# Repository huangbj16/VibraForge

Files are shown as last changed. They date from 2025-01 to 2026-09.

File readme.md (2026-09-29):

<h1 align="center">VibraForge</h1>

<p align="center">
  <strong>A Scalable Prototyping Toolkit for Creating Spatialized Vibrotactile Feedback Systems</strong>
</p>

<p align="center">
  
  
  
  
</p>

---

VibraForge is an open-source toolkit for building **spatialized vibrotactile (haptic) feedback systems**. Small vibration actuators (LRA / VCA) are daisy-chained into scalable arrays and driven wirelessly over Bluetooth Low Energy by an ESP32-based control unit. This repository shares the complete design — mechanical, electrical, firmware, and software — so you can reproduce, modify, and integrate the toolkit into your own research and applications.

The data flow through the system is:

```
Authoring tool (GUI Editor / Unity / Python)  →  Python BLE server  →  ESP32 Control Unit (BLE)  →  chain of Vibration Units (LRA/VCA)
```

## Table of Contents

- [Repository Structure](#repository-structure)
- [Getting Started](#getting-started)
- [Running the Software](#running-the-software)
- [Hardware Notes & Debugging](#hardware-notes--debugging)
- [Getting a Dev Kit](#getting-a-dev-kit)
- [Contributing](#contributing)
- [License](#license)
- [Citation](#citation)

## Repository Structure

| Directory | Description |
|---|---|
| [Electrical_Design/](Electrical_Design/) | PCB design files (EasyEDA / Altium / Gerber) and microcontroller firmware for the control and vibration units. |
| [Mechanical_Design/](Mechanical_Design/) | 3D-printable CAD (STL / 3MF) enclosures, caps, mounts, and rings. |
| [Software_Design/](Software_Design/) | Python BLE servers and the Unity Engine integration API. |
| [GUI_Editor/](GUI_Editor/) | PyQt6 desktop app for designing, simulating, and playing haptic waveforms. |
| [manufacturing.md](manufacturing.md) | End-to-end build guide — pipeline flowchart, full BOM, PCB ordering, firmware, and assembly. |

Each subfolder contains its own `readme` with detailed, component-specific instructions.

## Getting Started

There are two ways to get the hardware, depending on whether you already have a kit:

### ▸ I have a dev kit

If you received a hardware dev kit from the authors, it ships with a printed **[Quickstart Guide](quickstart_guide.pdf)** — follow it to get up and running quickly.

### ▸ I want to build it myself

If you don't have a kit, the **[Manufacturing Guide](manufacturing.md)** walks you through the entire build end-to-end: a step-by-step pipeline flowchart, a full bill of materials, ordering assembled PCBs from JLCPCB, flashing firmware, 3D-printing the enclosures, and final assembly.

At a high level:

1. **Fabricate the boards** — order the PCBs from the Gerber files in [Electrical_Design/](Electrical_Design/) and flash the firmware (Arduino for the control unit, MPLAB X for the vibration units).
2. **Print the enclosures** — print the CAD parts in [Mechanical_Design/](Mechanical_Design/).
3. **Assemble and test** — wire the chains and run the bring-up test (below).

> Prefer to skip fabrication? You can request a ready-made kit — see [Getting a Dev Kit](#getting-a-dev-kit).

## Running the Software

Once the hardware is assembled:

1. **Bring-up test** — verify BLE control with [`Python_Test.py`](Software_Design/Python_Server/Python_Test.py). Enter vibration parameters manually on the command line. Ensure the `CHARACTERISTIC_UUID` and control unit name match the values in the control unit's Arduino firmware:

   ```bash
   python Python_Test.py -uuid CUSTOM_UUID -name CONTROL_UNIT_NAME

   # default uuid = 'f22535de-5375-44bd-8ca9-d0ea9ff9e410'
   # default name = 'QT Py ESP32-S3'
   ```

2. **Design waveforms** — once the test passes, use the [GUI Editor](GUI_Editor/) to experiment with different vibration waveforms (Sine, PWM, Triangle, Saw, etc.).

3. **Integrate with Unity** — to drive vibrations from a game engine, use the [Unity Engine API](Software_Design/Unity_Engine_API/).

For details on each program, see the [Software_Design](Software_Design/) and [GUI_Editor](GUI_Editor/) readmes.

## Hardware Notes & Debugging

### Control Unit

- **Connector orientation matters.** The order of the four chain connectors is shown in the figure below, and the USB port should face **left**. Installing a connector in the wrong direction may short the ESP32 MCU.
- If the MCU misbehaves for no clear reason, try a [factory reset](https://learn.adafruit.com/adafruit-qt-py-esp32-s3/factory-reset).

<p align="center">Control unit assembly and connector orientation</p>

### Vibration Unit

- **Addressing.** Unit addresses start at **0** and are unique per chain position. Up to 16 units per chain: chain 1 → `0–15`, chain 2 → `16–31`, and so on.
- **Orientation matters.** With the programming pins on top, the **input is on the left** and the **output is on the right**. Do not reverse the order, or the driver board may be damaged by a short.
- **Status LED.** Each driver PCB has one RGB status LED (NeoPixel). It stays off while the unit is idle, lights up when the unit receives a "Start" command and should be vibrating, with the color indicating the intensity level, and turns off again on "Stop". It does not indicate power on its own. This is useful for checking MCU status while debugging.

<p align="center">Vibration unit chain addressing and orientation</p>

## Getting a Dev Kit

Interested in using the toolkit but would rather not build the hardware yourself? Request a development kit from the authors by filling out [this Google Form](https://forms.gle/6aN7M9MWAf4sLqWE6).

## Contributing

Contributions and bug reports are welcome! If you run into a problem or spot a bug while using the toolkit, please [open an issue](../../issues) — the authors will try to resolve it as soon as possible. Pull requests for improvements are also appreciated.

## License

This project is released under the [MIT License](LICENSE).

## Citation

If you use VibraForge in your research, we would appreciate it if you can cite our CHI 2025 paper:

```bibtex
@inproceedings{huang2025vibraforge,
  title={VibraForge: A Scalable Prototyping Toolkit For Creating Spatialized Vibrotactile Feedback Systems},
  author={Huang, Bingjian and Ren, Siyi and Luo, Yuewen and Cheng, Qilong and Cai, Hanfeng and Sang, Yeqi and Sousa, Mauricio and Dietz, Paul H and Wigdor, Daniel},
  booktitle={Proceedings of the 2025 CHI Conference on Human Factors in Computing Systems},
  pages={1--18},
  year={2025}
}
```

Have fun with the toolkit! 🎉

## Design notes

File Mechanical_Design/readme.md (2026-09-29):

# Mechanical Design

This folder contains CAD files for control units and vibration units. In our lab environment, parts are printed with PLA materials using 0.4mm nozzles on [Bambu Lab X1C 3D Printer](store.bambulab.com/collections/3d-printer/products/x1-carbon). Other printers with higher precision should also satisfy the requirements.

- Control_Unit_Large
- Control_Unit_Small — two enclosure variants with the same 49 × 47 mm footprint. Print each enclosure together with its matching cap.
  - **With battery** (`Enclosure_with_Battery.stl`, `Cap_with_Battery.stl`): the original design, with space for a battery. The enclosure is 22 mm tall and the cap 8.5 mm. STL only. These files were previously named `Enclosure.stl` and `Cap.stl`.
  - **Battery-free** (`Enclosure_Battery_Free.stl`, `Cap_Battery_Free.stl`) — **used in the dev kit**: a newer, slimmer design for a control unit powered over USB with no battery. The enclosure is 8.5 mm shallower (13.5 mm tall) and the cap is 11.5 mm tall. Editable STEP files are included.
- Vibration_Unit_LRAX
- Vibration_Unit_LRAZ
- Vibration_Unit_VCA

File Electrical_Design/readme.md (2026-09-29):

# Electrical Engineering Section ##

The electrical engineering section includes PCB design files for control units and vibration units, and main programs for microcontrollers. All PCB design were initially finished in [EasyEDA](https://easyeda.com/) and later exported to different formats. If you want to manufacture the board with PCB factories such as [JLCPCB](https://jlcpcb.com/) or [PCBWay](https://www.pcbway.com/), simply use the Gerber files. If you want to revise the design, Import the design files into EasyEDA Editor or Altium Designer.

Control units include the large unit and the small unit, with different ESP32 microcontrollers. The large unit uses [Adafruit ESP32 Feather V2](https://learn.adafruit.com/adafruit-esp32-feather-v2). The small unit uses [Adafruit QT Py ESP32-S3](https://learn.adafruit.com/adafruit-qt-py-esp32-s3). The Arduino programs are very similar, except the software serial pins are configured differently.

Arduino Library Rrquirements:
- [Arduino ESP32 support](https://github.com/espressif/arduino-esp32)
- [SoftwareSerial for ESP32](https://github.com/plerup/espsoftwareserial)

Vibration units include LRA and VCA, all using the PIC16F18313 8-pin microcontroller. The main program is the same across all vibration units. To program / reprogram the MCU, you need to download the [MPLAB X IDE](https://www.microchip.com/en-us/tools-resources/develop/mplab-x-ide) and buy the  [MPLAB® PICkit™ 5 In-Circuit Debugger](https://www.microchip.com/en-us/development-tool/pg164150). add the main program (`Vibration_Unit.c`) and the NeoPixel driver (`neopixel_control.c`, `neopixel_control.h`) to an MPLAB X project, connect the programming pins from the debugger to the top of the PCB board, following this [quickstart guideline](https://ww1.microchip.com/downloads/aemDocuments/documents/DEV/ProductDocuments/Brochures/MPLAB-PICkit-5-In-Circuit-Debugger-Quick-Start-Guide-50003478.pdf).

- Control_Unit
  - Large_Unit
  - Small_Unit
  - Main_Program_Arduino
    - BLE_peripheral_ESP32V2
    - BLE_peripheral_QTPyS3
- Vibration_Unit
  - Board_LRA
  - Board_VCA
  - Main_Program_MPLABXIDE
    - tests
  - Schematic

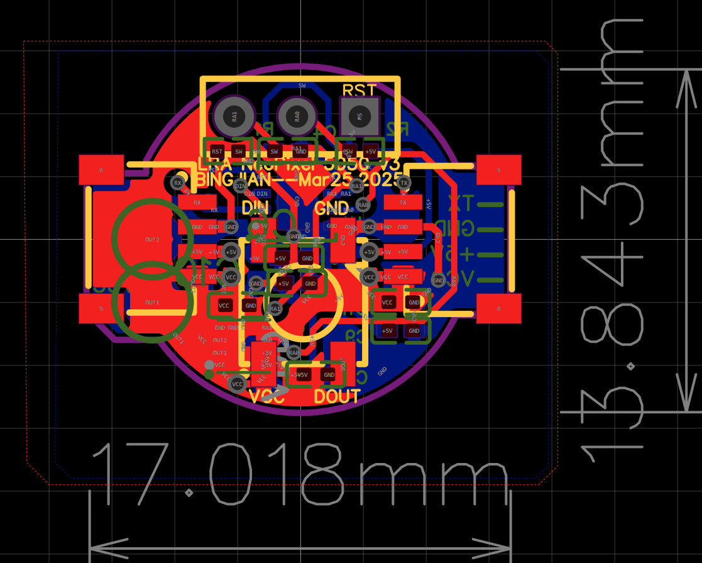
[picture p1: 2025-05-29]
Electrical_Design/Vibration_Unit/Board_LRA/Board_LRA_Screenshot.png

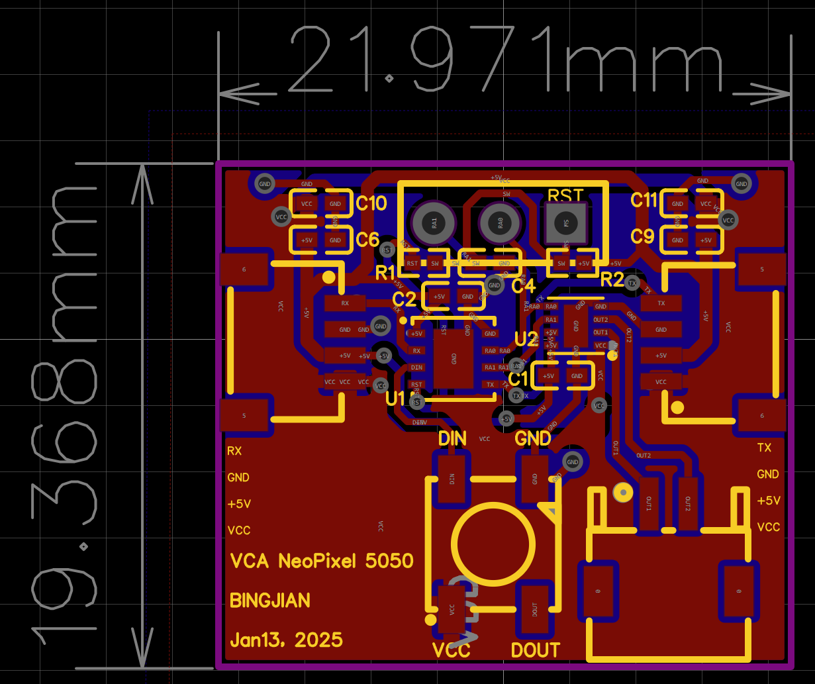
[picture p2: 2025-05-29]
Electrical_Design/Vibration_Unit/Board_VCA/Board_VCA_Screenshot.png

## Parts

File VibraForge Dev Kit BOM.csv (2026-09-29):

Item | # needed for a dev kit | Link
Packaging
fold box | 1 | https://www.amazon.ca/dp/B08G8CLKNH?ref_=ppx_hzsearch_conn_dt_b_fed_asin_title_1
3D print holder | 1 | https://www.amazon.ca/dp/B0FD1LFGZT (matte PLA filament)
sleeves | 1 | https://www.amazon.ca/dp/B0DGQ37KB7?ref=ppx_yo2ov_dt_b_fed_asin_title&th=1
rubber band | 1 | random
user manual | 1 | paper print
Control Unit
3D print enclosure (battery-free) | 1 | https://www.amazon.ca/dp/B0FGD7DJ4K (transparent PLA filament)
3D print cap (battery-free) | 1 | https://www.amazon.ca/dp/B0FGD7DJ4K (transparent PLA filament)
Controller PCB (v2.0) | 1 | https://jlcpcb.com/ (order as assembled PCBA)
Adafruit QT Py ESP32-S3 | 1 | https://www.adafruit.com/product/5426
Vibration Unit
LRA actuators | 10 | https://www.digikey.com/en/products/detail/jie-yi-electronics-limited/JYLRA9595X/22519430 (or Jinlong Machinery; bulk: contact author)
vibration PCB | 10 | https://jlcpcb.com/ (order as assembled PCBA)
3D print mount | 10 | https://www.amazon.ca/dp/B0FGD7DJ4K (transparent PLA filament)
cap | 10 | https://www.amazon.ca/dp/B0FGD7DJ4K (transparent PLA filament)
enclosure | 10 | https://www.amazon.ca/dp/B0FGD7DJ4K (transparent PLA filament)
ring | 10 | https://www.amazon.ca/dp/B0FGD7DJ4K (transparent PLA filament)
STEMMA QT / Qwiic JST SH 4-pin Cable - 100mm Long | 40 | https://www.adafruit.com/product/4210
MISC
PicKit5 programmer | 1 | https://www.digikey.com/en/products/detail/microchip-technology/PG164150/19915398

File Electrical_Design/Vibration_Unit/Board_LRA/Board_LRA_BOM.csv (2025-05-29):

ID | Name | Designator | Footprint | Quantity | Manufacturer Part | Manufacturer | Supplier | Supplier Part | Price
1 | CONN-SMD_YTC1P-3015-01 | U6,U4 | CONN-SMD_YTC1P-3015-01 | 2 | YTC1P-3015-01 | YIYUAN(怡远) | LCSC | C5221293 | 0.112
2 | 1uF | C1 | C0402 | 1 | CL05A105KA5NQNC | SAMSUNG(三星) | LCSC | C52923 | 0.003
3 | 100nF | C2,C4 | C0402_NEW | 2 | CL05B104KO5NNNC | SAMSUNG(三星) | LCSC | C1525 | 0.001
4 | 300Ω | R1 | R0402 | 1 | 0402WGF3000TCE | UNI-ROYAL(厚声) | LCSC | C25102 | 0.001
5 | 10kΩ | R2 | R0402 | 1 | 0402WGF1002TCE | UNI-ROYAL(厚声) | LCSC | C25744 | 0.001
6 | PIC16F18313-E/RF | U1 | DFN-8_L3.0-W3.0-P0.65-BL-EP | 1 | PIC16F18313-E/RF | MICROCHIP(美国微芯) | LCSC | C635328 | 2.104
7 | DRV8837DSGR | U2 | WSON-8_L2.0-W2.0-P0.50-TL-EP | 1 | DRV8837DSGR | TI(德州仪器) | LCSC | C39159 | 0.141
8 | LED-SMD_4P-L5.0-W5.0-TL-2 | U3 | LED-SMD_4P-L5.0-W5.0-TL-2 | 1 | SKC6812RGBW-BW-B | 欧思科光电 | LCSC | C5380878 | 0.141
9 | SM04B-SRSS-TB (LF)(SN) | CN5,CN6 | CONN-SMD_4P-P1.00_SM04B-SRSS-TB-LF-SN | 2 | SM04B-SRSS-TB(LF)(SN) | JST | LCSC | C160404 | 0.191
10 | C0402 | C6,C9,C10,C11 | C0402 | 4 | GRM155R60J226ME11D | muRata(村田) | LCSC | C415703 | 0.037

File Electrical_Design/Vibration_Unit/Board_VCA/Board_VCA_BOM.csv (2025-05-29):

ID | Name | Designator | Footprint | Quantity | Manufacturer Part | Manufacturer | Supplier | Supplier Part | Price
1 | LED-SMD_4P-L5.0-W5.0-TL-2 | U3 | LED-SMD_4P-L5.0-W5.0-TL-2 | 1 | SKC6812RGBW-BW-B | 欧思科光电 | LCSC | C5380878 | 0.141
2 | S2B-ZR-SM4A-TF(LF)(SN) | CN2 | CONN-SMD_S2B-ZR-SM4A | 1 | S2B-ZR-SM4A-TF(LF)(SN) | JST | LCSC | C265329 | 0.173
3 | 1uF | C1 | C0402 | 1 | CL05A105KA5NQNC | SAMSUNG(三星) | LCSC | C52923 | 0.003
4 | 100nF | C2,C4 | C0402_NEW | 2 | CL05B104KO5NNNC | SAMSUNG(三星) | LCSC | C1525 | 0.001
5 | SM04B-SRSS-TB (LF)(SN) | CN5,CN6 | CONN-SMD_4P-P1.00_SM04B-SRSS-TB-LF-SN | 2 | SM04B-SRSS-TB(LF)(SN) | JST | LCSC | C160404 | 0.191
6 | 300Ω | R1 | R0402 | 1 | 0402WGF3000TCE | UNI-ROYAL(厚声) | LCSC | C25102 | 0.001
7 | 10kΩ | R2 | R0402 | 1 | 0402WGF1002TCE | UNI-ROYAL(厚声) | LCSC | C25744 | 0.001
8 | PIC16F18313-E/RF | U1 | DFN-8_L3.0-W3.0-P0.65-BL-EP | 1 | PIC16F18313-E/RF | MICROCHIP(美国微芯) | LCSC | C635328 | 2.104
9 | DRV8837DSGR | U2 | WSON-8_L2.0-W2.0-P0.50-TL-EP | 1 | DRV8837DSGR | TI(德州仪器) | LCSC | C39159 | 0.141
10 | C0402 | C6,C9,C10,C11 | C0402 | 4 | GRM155R60J226ME11D | muRata(村田) | LCSC | C415703 | 0.037

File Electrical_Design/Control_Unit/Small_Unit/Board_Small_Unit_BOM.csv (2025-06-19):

ID | Name | Designator | Footprint | Quantity | Manufacturer Part | Manufacturer | Supplier | Supplier Part | Price
1 | B5819W_C8598 | D3 | SOD-123_L2.7-W1.6-LS3.7-RD-1 | 1 | B5819W SL | CJ(江苏长电/长晶) | LCSC | C8598 | 0.023
2 | 22uF | C5 | CAP-SMD_BD5.0-L5.3-W5.3-FD | 1 | RVT1E220M0505 | HONOR(荣誉) | LCSC | C15848 | 0.029
3 | 22uH | L2 | IND-SMD_L6.0-W6.0_SWPA6045S | 1 | SWPA6045S220MT | Sunlord(顺络) | LCSC | C83454
4 | S2B-PH-K-S-GW | U4,U5 | CONN-TH_S2B-PH-K-S-GW | 2 | S2B-PH-K-S-GW | JST | LCSC | C157932 | 0.197
5 | 1uF | C2,C1 | C0805 | 2 | CL21B105KBFNNNE | SAMSUNG(三星) | LCSC | C28323 | 0.009
6 | 10nF | C3,C7 | C0402 | 2 | CL05B103KB5NNNC | SAMSUNG(三星) | LCSC | C15195 | 0.001
7 | 10uF | C4 | C0603 | 1 | CL10A106KP8NNNC | SAMSUNG(三星) | LCSC | C19702 | 0.006
8 | 2.2uF | C6 | C0603 | 1 | CL10A225KO8NNNC | SAMSUNG(三星) | LCSC | C23630 | 0.006
9 | 120uF | C9 | CAP-SMD_BD6.3-L6.6-W6.6-FD | 1 | 10SVPC120MV | PANASONIC(松下) | LCSC | C178336 | 0.959
10 | SS34_C8678 | D2,D1 | SMA_L4.3-W2.6-LS5.2-RD | 2 | SS34 | MDD(辰达半导体) | LCSC | C8678 | 0.028
11 | LM22675MRX-5.0/NOPB | U1 | SO-8_L4.9-W3.9-P1.27-LS6.0-BL-EP5.1 | 1 | LM22675MRX-5.0/NOPB | TI(德州仪器) | LCSC | C431550 | 1.155
12 | LT1763CS8-5#TRPBF | U3 | SO-8_L4.9-W3.9-P1.27-LS5.9-BL | 1 | LT1763CS8-5#TRPBF | ADI(亚德诺) | LCSC | C579850 | 5.477
13 | 22uF | C8 | C0805 | 1 | CL21A226MAYNNNE | SAMSUNG(三星) | LCSC | C602037 | 0.023
14 | SM04B-SRSS-TB (LF)(SN) | CN3,CN4,CHAIN#1,CN2 | CONN-SMD_4P-P1.00_SM04B-SRSS-TB-LF-SN | 4 | SM04B-SRSS-TB(LF)(SN) | JST | LCSC | C160404 | 0.191
15 | A2541HWV-7P | H1,H2 | HDR-TH_7P-P2.54-V_A2541HWV-7P | 2 | A2541HWV-7P | CJT(长江连接器) | LCSC | C225504 | 0.13
16 | SZYY0805YG | LED13 | LED0805-R-RD_GREEN | 1 | SZYY0805YG | yongyu(永裕光电) | LCSC | C434435 | 0.014
17 | 10kΩ | R13 | R0805 | 1 | 0805W8F1002T5E | UNI-ROYAL(厚声) | LCSC | C17414 | 0.002

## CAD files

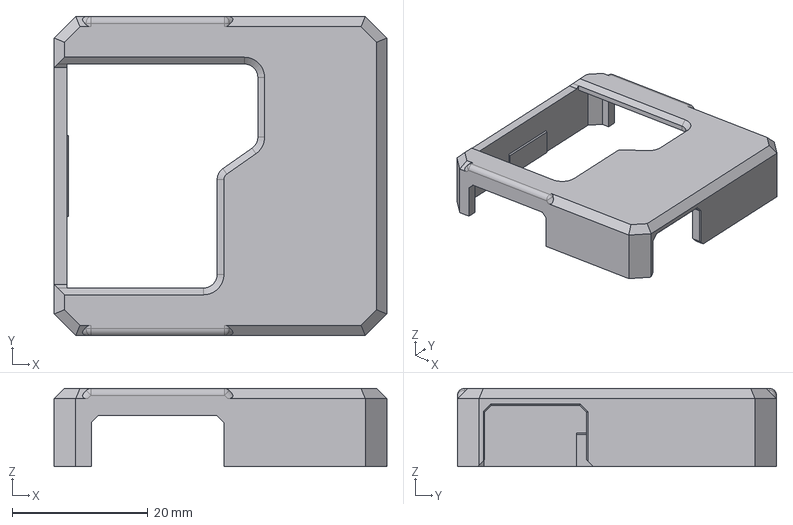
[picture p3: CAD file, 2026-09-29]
Mechanical_Design/Control_Unit_Small/Cap_Battery_Free.step
49.0 x 47.0 x 11.5 mm

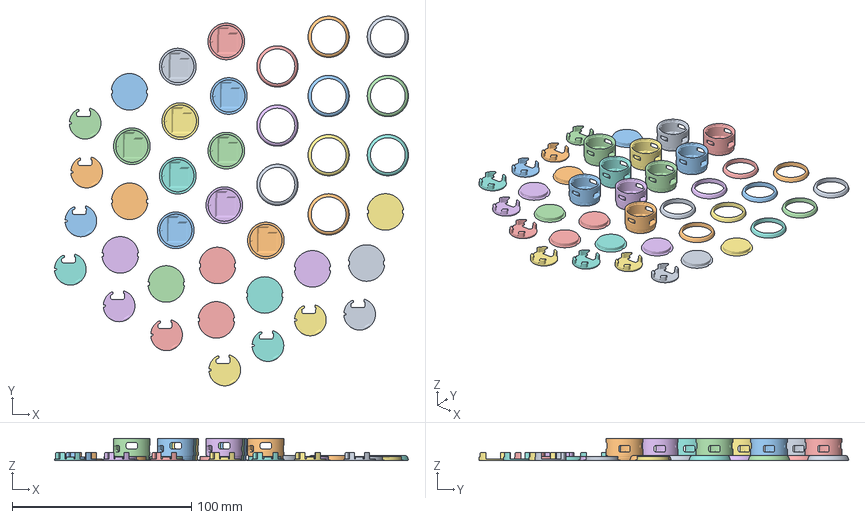
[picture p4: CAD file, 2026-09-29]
Mechanical_Design/Vibration_Unit_LRAX/printing_plate_unitx10.3mf
197.7 x 206.5 x 12.5 mm
Ring.stl x 10
Enclosure.stl x 10
Cap.stl x 10
Mount.stl x 10

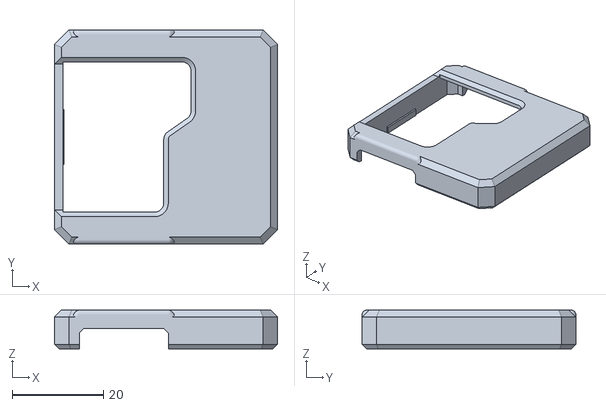
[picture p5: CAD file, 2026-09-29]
Mechanical_Design/Control_Unit_Small/Cap_with_Battery.stl
49.0 x 47.0 x 8.50

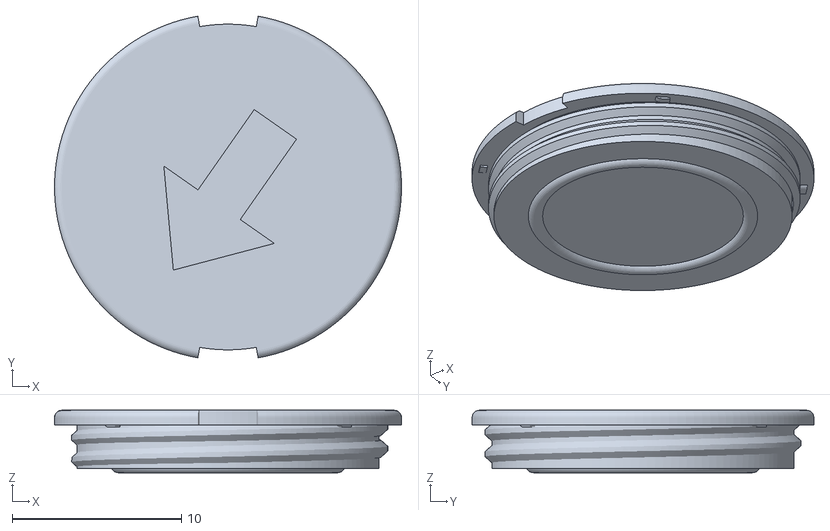
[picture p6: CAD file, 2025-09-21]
Mechanical_Design/Vibration_Unit_LRAX/Cap.stl
20.5 x 20.2 x 3.70

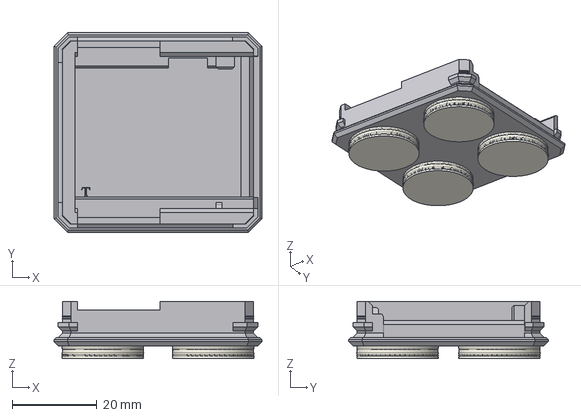
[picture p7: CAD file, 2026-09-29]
Mechanical_Design/Control_Unit_Small/Enclosure_Battery_Free.step
49.0 x 47.0 x 13.5 mm

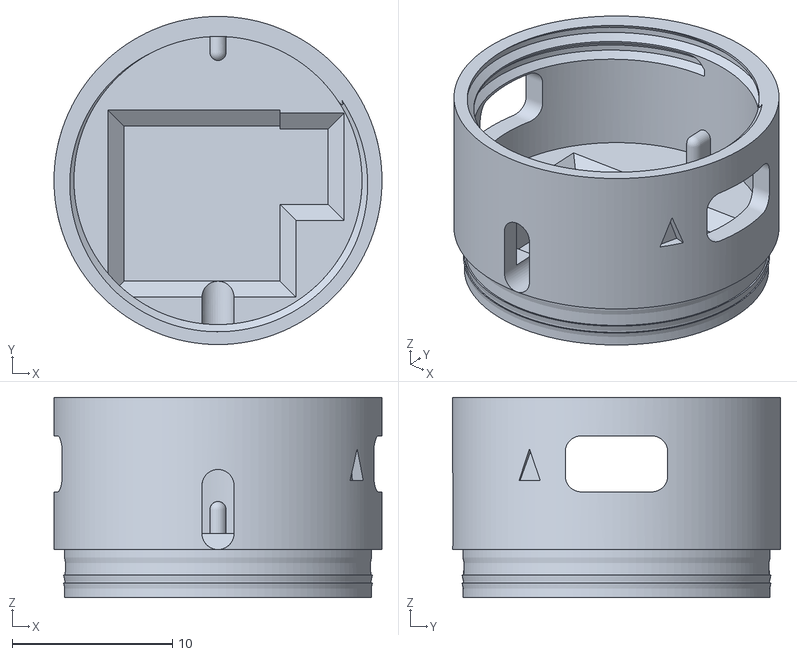
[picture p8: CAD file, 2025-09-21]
Mechanical_Design/Vibration_Unit_LRAX/Enclosure.stl
20.5 x 20.5 x 12.5

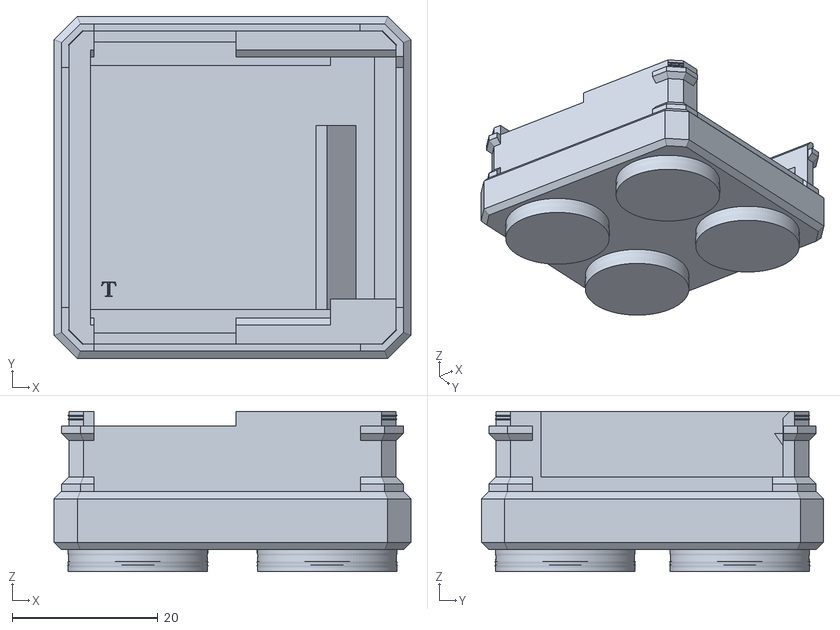
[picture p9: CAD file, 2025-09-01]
Mechanical_Design/Control_Unit_Small/Enclosure_with_Battery.stl
49.0 x 47.0 x 22.0

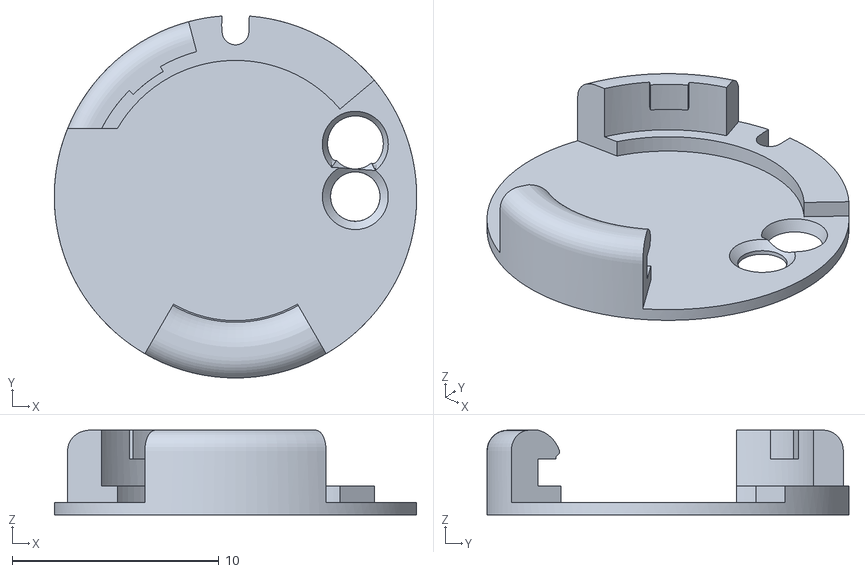
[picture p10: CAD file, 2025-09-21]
Mechanical_Design/Vibration_Unit_LRAX/Mount.stl
17.5 x 17.5 x 4.10

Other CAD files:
Mechanical_Design/Control_Unit_Small/Cap_Battery_Free.stl
Mechanical_Design/Control_Unit_Small/Enclosure_Battery_Free.stl

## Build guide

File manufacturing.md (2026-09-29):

# Manufacturing Guide

This document describes how to manufacture one **VibraForge** development kit end-to-end, so you can build a working spatialized vibrotactile system yourself. It covers PCB ordering, component sourcing, firmware programming, 3D-printed parts, and final assembly.

This guide targets the **standard dev-kit configuration**:

- **Control Unit** — 1×, based on the **Adafruit QT Py ESP32-S3** (the "Small" control unit). A Bluetooth hub that drives up to four serial chains of actuators.
- **Vibration Units** — 10×, each a PIC-microcontroller driver board carrying one **LRA-X** actuator (linear resonant actuator, in-plane axis). Units are daisy-chained; each chain supports up to 16 units.
- **Packaging** — box, holder, sleeves, and printed manual for shipping a complete kit.

> Source files: PCB + firmware in [Electrical_Design/](Electrical_Design/), CAD in [Mechanical_Design/](Mechanical_Design/).

---

## 1. Manufacturing Pipeline (DAG)

The three sub-assemblies — **Packaging**, **Control Unit**, and **Vibration Units** — are fully independent and can be built in parallel. They converge only at final kit assembly and bring-up test.

```mermaid
---
title: VibraForge Dev Kit — Manufacturing Pipeline
---
flowchart LR
    START([" Start<br/>build one dev kit "]):::milestone

    %% ===================== CONTROL UNIT (top lane) =====================
    subgraph CU ["🎛️ Control Unit ×1"]
        direction LR
        C1[/"Order Controller PCB v2.0 · JLCPCB<br/>assembled PCBA · ~7 business days<br/>⏱ ORDER EARLY"/]:::buy
        C2[/"Buy QT Py ESP32-S3<br/>Adafruit / DigiKey"/]:::buy
        C3["3D-print battery-free<br/>enclosure + cap<br/>100% infill · 0.2 mm layer"]:::print
        C4["Program ESP32<br/>Arduino IDE"]:::program
        C2 --> C4
        C4 --> C5["Mount ESP32 on PCB"]:::assemble
        C1 --> C5
        C5 --> C6["Assemble into<br/>enclosure + cap"]:::assemble
        C3 --> C6
        C6 --> CU_DONE(["✔ Control Unit ready"]):::milestone
    end

    %% ===================== VIBRATION UNITS (middle lane) =====================
    subgraph VU ["📳 Vibration Units ×10"]
        direction LR
        V1[/"Source LRA-X actuators ×10<br/>Jinlong Machinery / DigiKey"/]:::buy
        V2[/"Order Vibration PCB ×10 · JLCPCB<br/>assembled PCBA · ~7 business days<br/>⏱ ORDER EARLY"/]:::buy
        V4["3D-print mount + cap<br/>+ enclosure + ring · ×10 each<br/>100% infill · 0.12 mm layer"]:::print
        V5["Program PIC16F18313<br/>PICkit 5 · flash firmware<br/>wiring → Sec 3.3.1"]:::program
        V2 --> V5
        V5 --> V6["Assemble · NO SOLDERING<br/>actuator via pogo-pin contact<br/>PCB into enclosure/mount/ring/cap"]:::assemble
        V1 --> V6
        V4 --> V6
        V6 --> VU_DONE(["✔ Vibration Units ready"]):::milestone
    end

    %% ===================== PACKAGING (bottom lane) =====================
    subgraph PKG ["📦 Packaging"]
        direction LR
        P1[/"Buy fold box ×1<br/>Amazon"/]:::buy
        P2[/"Buy sleeves ×1<br/>Amazon"/]:::buy
        P3[/"Buy rubber band ×1"/]:::buy
        P4["3D-print holder ×1"]:::print
        P5["Print user manual<br/>on paper ×1"]:::print
        P1 --> PKG_DONE
        P2 --> PKG_DONE
        P3 --> PKG_DONE
        P4 --> PKG_DONE
        P5 --> PKG_DONE
        PKG_DONE(["✔ Packaging ready"]):::milestone
    end

    %% ===================== INTEGRATION (right column) =====================
    subgraph INT ["🔗 Integration & Test"]
        direction TB
        BUYCABLE[/"Buy JST SH 4-pin cables ×40<br/>Adafruit / DigiKey"/]:::buy
        WIRE["Wire chains<br/>units in series via JST cables<br/>plug chains into control unit"]:::assemble
        TEST["Bring-up test<br/>Python_Test.py over BLE"]:::test
        PACK["Pack into box<br/>holder · sleeves · manual"]:::assemble
        DONE([" ✔ Dev kit complete "]):::milestone
        BUYCABLE --> WIRE
        WIRE --> TEST
        TEST --> PACK
        PACK --> DONE
    end

    START --> C1
    START --> V1
    START --> P1

    CU_DONE --> WIRE
    VU_DONE --> BUYCABLE
    PKG_DONE --> PACK

    %% ===================== STYLING =====================
    classDef buy       fill:#E3F2FD,stroke:#1565C0,stroke-width:1px,color:#0D47A1;
    classDef print     fill:#E8F5E9,stroke:#2E7D32,stroke-width:1px,color:#1B5E20;
    classDef program   fill:#FFF3E0,stroke:#EF6C00,stroke-width:1px,color:#E65100;
    classDef assemble  fill:#F3E5F5,stroke:#6A1B9A,stroke-width:1px,color:#4A148C;
    classDef test      fill:#FCE4EC,stroke:#AD1457,stroke-width:1px,color:#880E4F;
    classDef milestone fill:#263238,stroke:#263238,stroke-width:1px,color:#FFFFFF;
    style CU  fill:#FAFAFA,stroke:#CFD8DC,stroke-width:1px,color:#37474F;
    style VU  fill:#FAFAFA,stroke:#CFD8DC,stroke-width:1px,color:#37474F;
    style PKG fill:#FAFAFA,stroke:#CFD8DC,stroke-width:1px,color:#37474F;
    style INT fill:#F5F5F5,stroke:#90A4AE,stroke-width:1.5px,color:#37474F;
```

**Critical path:** the two JLCPCB orders (Controller PCB and Vibration PCBs) have the longest lead time at **~7 business days** — place both first, then print 3D parts, buy off-the-shelf items, and program firmware while you wait.

---

## 2. Bill of Materials (one dev kit)

> The full parts list is also available as a spreadsheet: [VibraForge Dev Kit BOM.csv](VibraForge%20Dev%20Kit%20BOM.csv).
>
> **Filament:** print the packaging **holder** in [matte PLA](https://www.amazon.ca/dp/B0FD1LFGZT); print **all other parts** (control-unit and vibration-unit enclosures, caps, mounts, rings) in [transparent PLA](https://www.amazon.ca/dp/B0FGD7DJ4K).

### Packaging
| Item | Qty | Source |
|---|-----|---|
| Fold box | 1 | [Amazon](https://www.amazon.ca/dp/B08G8CLKNH) |
| Sleeves | 1 | [Amazon](https://www.amazon.ca/dp/B0DGQ37KB7) |
| Rubber band | 1 | Any |
| 3D-print holder | 1 | Print in-house |
| User manual | 1 | Paper print |

### Control Unit (×1)
| Item | Qty | Source |
|---|-----|---|
| Controller PCB v2.0 (assembled) | 1 | JLCPCB (PCBA) |
| Adafruit QT Py ESP32-S3 | 1 | [Adafruit #5426](https://www.adafruit.com/product/5426) / DigiKey |
| 3D-print enclosure (battery-free) | 1 | Print in-house |
| 3D-print cap (battery-free) | 1 | Print in-house |

### Vibration Unit (×10)
| Item | Qty | Source |
|---|-----|---|
| LRA-X actuator | 10 | Jinlong Machinery / [DigiKey JYLRA9595X](https://www.digikey.com/en/products/detail/jie-yi-electronics-limited/JYLRA9595X/22519430) — for bulk orders, contact the author |
| Vibration PCB (assembled) | 10 | JLCPCB (PCBA) |
| 3D-print mount | 10 | Print in-house |
| 3D-print cap | 10 | Print in-house |
| 3D-print enclosure | 10 | Print in-house |
| 3D-print ring | 10 | Print in-house |
| STEMMA QT / Qwiic JST SH 4-pin cable, 100mm | 40 | [Adafruit #4210](https://www.adafruit.com/product/4210) / DigiKey |

### Miscellaneous (tools — one per builder, not per kit)
| Item | Qty | Source |
|---|-----|---|
| MPLAB PICkit 5 programmer | 1 | [DigiKey PG164150](https://www.digikey.com/en/products/detail/microchip-technology/PG164150/19915398) |

> Both PCBs are ordered **fully assembled (PCBA)** from JLCPCB, so no hand-soldering of SMT components is required. The orderable BOM and placement files are provided for both boards:
> - Small Control Unit: [Board_Small_Unit_BOM.csv](Electrical_Design/Control_Unit/Small_Unit/Board_Small_Unit_BOM.csv), [Board_Small_Unit_CPL.csv](Electrical_Design/Control_Unit/Small_Unit/Board_Small_Unit_CPL.csv)
> - LRA Vibration Unit: [Board_LRA_BOM.csv](Electrical_Design/Vibration_Unit/Board_LRA/Board_LRA_BOM.csv), [Board_LRA_CPL.csv](Electrical_Design/Vibration_Unit/Board_LRA/Board_LRA_CPL.csv)

---

## 3. Step-by-Step Manufacturing

### 3.1 Packaging

All three sub-assemblies are independent — packaging can be prepared any time.

1. **Buy** the fold box, sleeves, and a rubber band (see BOM links).
2. **3D-print** the packaging holder (1×).
3. **Print the user manual** on paper.
4. Set these aside for final kit assembly (§3.5).

### 3.2 Control Unit (×1)

1. **Order the Controller PCB v2.0** from [JLCPCB](https://jlcpcb.com/) as an **assembled PCBA** — upload the Gerber, BOM, and CPL from [Small_Unit/](Electrical_Design/Control_Unit/Small_Unit/) so JLCPCB places all components. **Lead time ~7 business days — order this first.**
2. **Buy the Adafruit QT Py ESP32-S3** ([#5426](https://www.adafruit.com/product/5426), Adafruit or DigiKey).
3. **3D-print** the **battery-free** control-unit enclosure and cap — [Enclosure_Battery_Free.stl](Mechanical_Design/Control_Unit_Small/Enclosure_Battery_Free.stl) and [Cap_Battery_Free.stl](Mechanical_Design/Control_Unit_Small/Cap_Battery_Free.stl) — normal settings with **100% infill** and a regular **0.2mm layer height**. The unit is powered over USB. The folder also contains the older `*_with_Battery` variant, which the dev kit does not use (see the [Mechanical Design readme](Mechanical_Design/readme.md)).
4. **Program the ESP32 with Arduino IDE** (see §3.2.1).
5. **Assemble:** mount the programmed ESP32 onto the controller PCB, then fit the PCB into the enclosure and close with the cap.
6. **Orientation matters:** the four chain connectors must be installed in the correct order and the **USB port must face left** — see [Figures/control_unit.png](Figures/control_unit.png). Reversing a connector can short the ESP32.

#### 3.2.1 Control Unit Firmware (Arduino)

1. Install the [Arduino ESP32 core](https://github.com/espressif/arduino-esp32) and the [ESP32 SoftwareSerial](https://github.com/plerup/espsoftwareserial) library. The sketch also uses `ArduinoJson` and `Adafruit_NeoPixel`.
2. Open [BLE_peripheral_QTPyS3.ino](Electrical_Design/Control_Unit/Main_Program_Arduino/BLE_peripheral_QTPyS3/BLE_peripheral_QTPyS3.ino).
3. Note the BLE identifiers — these must match your host software:
   - `SERVICE_UUID = f10016f6-542b-460a-ac8b-bbb0b2010599`
   - `CHARACTERISTIC_UUID = f22535de-5375-44bd-8ca9-d0ea9ff9e410`
   - Device name: `QT Py ESP32-S3`
4. The four chains are driven on `subchain_pins = {18, 17, 9, 8}`.
5. Select the QT Py ESP32-S3 board and upload over USB. If it misbehaves, [factory-reset the board](https://learn.adafruit.com/adafruit-qt-py-esp32-s3/factory-reset).

### 3.3 Vibration Units (×10)

1. **Source the LRA-X actuators** (10×) from **Jinlong Machinery**, or buy from [DigiKey (JYLRA9595X)](https://www.digikey.com/en/products/detail/jie-yi-electronics-limited/JYLRA9595X/22519430). For bulk orders, contact the author.
2. **Order the Vibration PCBs** (10×) from JLCPCB as **assembled PCBA** — upload the Gerber, BOM, and CPL from [Board_LRA/](Electrical_Design/Vibration_Unit/Board_LRA/). **Lead time ~7 business days — order early.**
3. **Buy the JST cables:** STEMMA QT / Qwiic JST SH 4-pin, 100mm (40× — [Adafruit #4210](https://www.adafruit.com/product/4210) or DigiKey). These form the chain links.
4. **3D-print** all four parts — mount, cap, enclosure, ring (10× each) — normal settings with **100% infill** and **0.12mm layer height** (files in [Vibration_Unit_LRAX/](Mechanical_Design/Vibration_Unit_LRAX/)).
5. **Program each PIC16F18313 MCU** with the PICkit 5 (§3.3.1). The same firmware is flashed to every unit — no per-unit address to set.
6. **Assemble — no soldering required!** The LRA-X actuator makes contact with the PCB via **pogo pins**. Seat the actuator, PCB, mount, and ring into the enclosure and close with the cap; the ring/mount hold the actuator against the pogo-pin contacts.
7. **Orientation matters:** with the programming pins on top, **input is on the left, output on the right**. Do not reverse — the driver board can be damaged by a short. See [Figures/vibration_unit.png](Figures/vibration_unit.png).
8. **Status LED (debug aid):** each board has one RGB NeoPixel. It is off while idle and lights up when the board receives a "Start" command and should be vibrating, with the color indicating the intensity level. It does not indicate power on its own.

#### 3.3.1 Vibration Unit Firmware (PICkit 5)

The **same firmware** runs on every vibration unit: [Vibration_Unit.c](Electrical_Design/Vibration_Unit/Main_Program_MPLABXIDE/Vibration_Unit.c) plus the NeoPixel driver [neopixel_control.c](Electrical_Design/Vibration_Unit/Main_Program_MPLABXIDE/neopixel_control.c) / [neopixel_control.h](Electrical_Design/Vibration_Unit/Main_Program_MPLABXIDE/neopixel_control.h) (PIC16F18313, 32 MHz HFINTOSC). There is **no per-unit address to program** — a unit's address is determined automatically by its position in the chain at runtime (chain 1 → 0–15, chain 2 → 16–31, etc.).

1. Install [MPLAB X IDE](https://www.microchip.com/en-us/tools-resources/develop/mplab-x-ide) and connect the [PICkit 5](https://www.digikey.com/en/products/detail/microchip-technology/PG164150/19915398).
2. Connect the PICkit 5 programming wires to the header on the **top** of the vibration PCB as shown below:

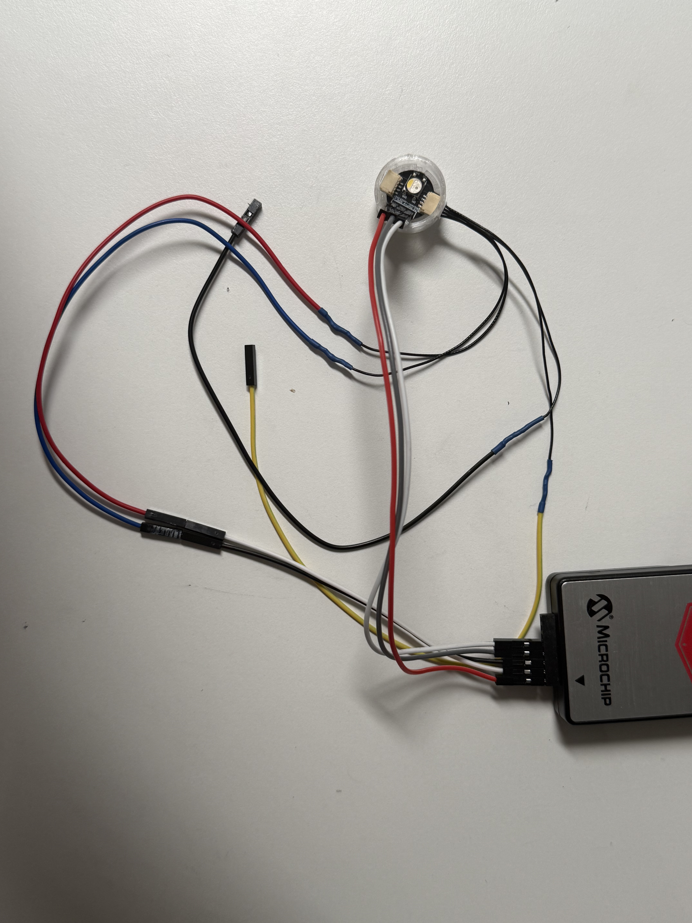
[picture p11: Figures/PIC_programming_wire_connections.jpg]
PICkit 5 to vibration unit programming wire connections
   

3. Create an MPLAB X project for the PIC16F18313 with the XC8 compiler and add `Vibration_Unit.c`, `neopixel_control.c`, and `neopixel_control.h` (not the standalone programs in `tests/`). Build and flash the firmware to each of the 10 boards. Every board gets the identical program.

### 3.4 Chain Wiring & Bring-up Test

1. **Daisy-chain the vibration units:** connect each unit's **output** to the next unit's **input** using the JST SH cables, keeping input-left / output-right orientation consistent.
2. Plug each chain's first unit into the corresponding chain connector on the control unit (respect connector order, §3.2).
3. Power the control unit via USB.
4. **Bring-up test** — install `pip install bleak`, then from [Software_Design/Python_Server/](Software_Design/Python_Server/):
   ```bash
   python Python_Test.py -uuid f22535de-5375-44bd-8ca9-d0ea9ff9e410 -name "QT Py ESP32-S3"
   ```
5. Send a command to a known address and confirm the target unit's NeoPixel lights up and it vibrates.

### 3.5 Final Kit Assembly

1. Place the tested control unit and 10 vibration units into the 3D-printed holder.
2. Add the sleeves and secure with the rubber band.
3. Insert the printed user manual and pack everything into the fold box.

Once verified, the kit can be driven with the [GUI Editor](GUI_Editor/), the [Unity API](Software_Design/Unity_Engine_API/), or [Python_Play_Command.py](Software_Design/Python_Server/Python_Play_Command.py).

---

## 4. Quick Checklist

**Order early (long lead time):**
- [ ] Controller PCB v2.0 — JLCPCB assembled (~7 business days)
- [ ] Vibration PCBs ×10 — JLCPCB assembled (~7 business days)

**Control Unit**
- [ ] QT Py ESP32-S3 purchased
- [ ] Battery-free enclosure + cap printed (100% infill, 0.2mm)
- [ ] ESP32 flashed with Arduino firmware
- [ ] Assembled (USB faces left, connector order verified)

**Vibration Units (×10)**
- [ ] LRA-X actuators sourced (Jinlong / DigiKey)
- [ ] Mount / cap / enclosure / ring printed (100% infill, 0.12mm)
- [ ] Each PIC flashed with firmware (PICkit 5, no address to set)
- [ ] Assembled — no soldering (pogo-pin actuator contact, input-left/output-right)

**Packaging**
- [ ] Fold box + sleeves + rubber band bought
- [ ] Holder printed, manual printed

**Integration**
- [ ] JST cables ×40 purchased
- [ ] Chains wired and plugged into control unit
- [ ] Passed `Python_Test.py` bring-up test
- [ ] Packed into box

Have fun building the toolkit! If you hit a problem, open an issue in the repository.

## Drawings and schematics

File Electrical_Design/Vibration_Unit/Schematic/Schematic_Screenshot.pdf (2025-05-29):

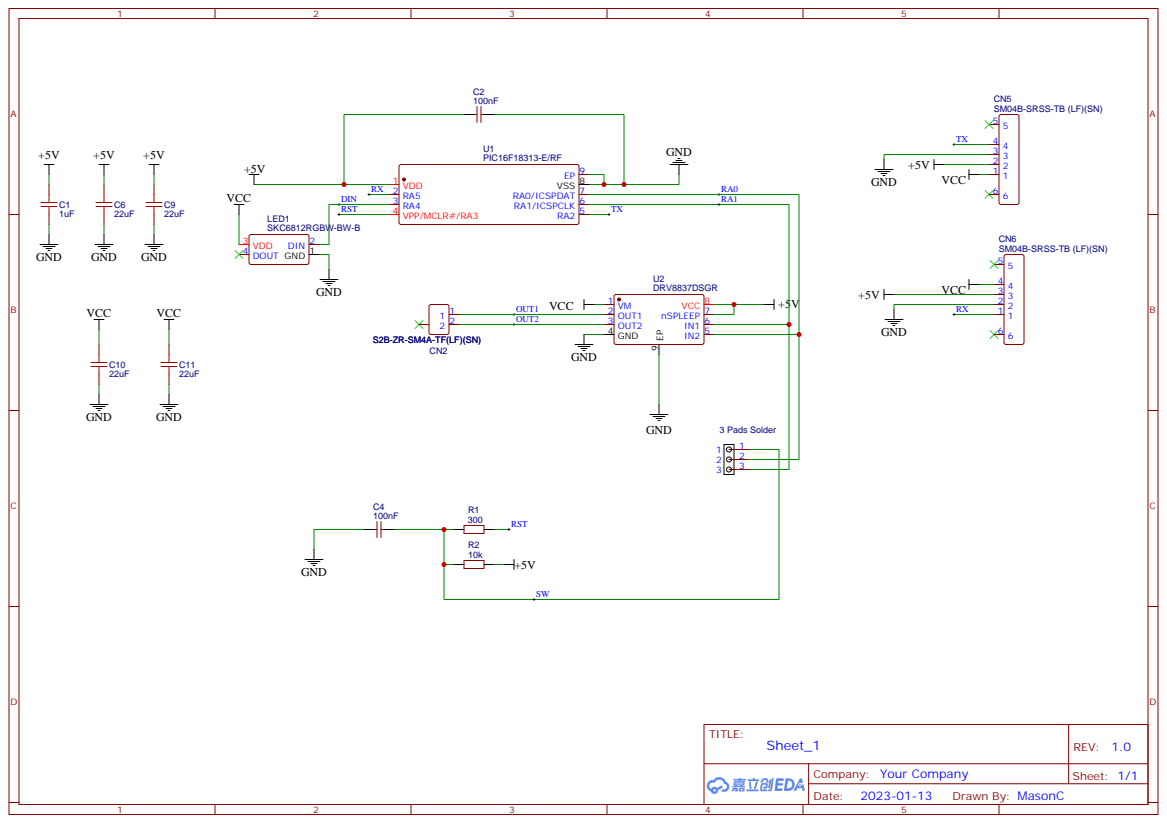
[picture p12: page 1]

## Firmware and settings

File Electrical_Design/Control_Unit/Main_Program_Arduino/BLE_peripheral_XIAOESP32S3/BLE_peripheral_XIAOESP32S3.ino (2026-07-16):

#include <BLEDevice.h>
#include <BLEUtils.h>
#include <BLEServer.h>
#include <BLEClient.h>
#include <ArduinoJson.h>
#include <SoftwareSerial.h>

// See the following for generating UUIDs:
// https://www.uuidgenerator.net/

#define SERVICE_UUID        "f10016f6-542b-460a-ac8b-bbb0b2010599"
#define CHARACTERISTIC_UUID "f22535de-5375-44bd-8ca9-d0ea9ff9e410"
//#define CURRENTSENSING_UUID "640b8bf5-3c88-44f6-95e0-f5813b390d73"
BLECharacteristic *csCharacteristic;

bool deviceConnected = false;

// ---------------------------------------------------------------------------
// PIN MAP: QT Py ESP32-S3  ->  XIAO ESP32-S3 (same physical pads)
//   QT Py A0 = GPIO18  ->  XIAO D0 = GPIO1
//   QT Py A1 = GPIO17  ->  XIAO D1 = GPIO2
//   QT Py A2 = GPIO9   ->  XIAO D2 = GPIO3   (NOTE: GPIO3 is a strapping pin)
//   QT Py A3 = GPIO8   ->  XIAO D3 = GPIO4
// GPIO numbers are used directly so this compiles under either the
// "XIAO_ESP32S3" or a generic "ESP32S3 Dev Module" board selection.
// ---------------------------------------------------------------------------
const int subchain_pins[4] = {1, 2, 3, 4};  // physical pads D0, D1, D2, D3
const int subchain_num = 4;
int global_counter = 0;

// The XIAO ESP32-S3 has a single onboard user LED on GPIO21 (active LOW).
// It has NO addressable RGB NeoPixel, so the QT Py NeoPixel code is removed
// and replaced with this plain status LED.
#define STATUS_LED 21

EspSoftwareSerial::UART serial_group[4];

class MyCharacteristicCallbacks: public BLECharacteristicCallbacks {
  void onWrite(BLECharacteristic *pCharacteristic) {
      String value = pCharacteristic->getValue();
      if (value.length() % 3 == 0) {  // Ensure the length is a multiple of 3 bytes
          unsigned long timestamp = millis(); // Get current time in milliseconds
          Serial.print("Timestamp: ");
          Serial.print(timestamp);
          Serial.print(" ms, Data = ");
          Serial.print(value.length());
          Serial.print(" bytes, # = ");
          Serial.println(++global_counter);
  
          for (int i = 0; i < value.length(); i += 3) {
              uint8_t byte1 = value[i];
              uint8_t byte2 = value[i+1];
              uint8_t byte3 = value[i+2];
  
              if (byte1 == 0xFF) continue; // Skip if the first byte of the command is 0xFF
  
              int serial_group_number = (byte1 >> 2) & 0x0F;
              int is_start = byte1 & 0x01;
              int addr = byte2 & 0x3F;
              int duty = (byte3 >> 3) & 0x0F;
              int freq = (byte3 >> 1) & 0x03;
              int wave = byte3 & 0x01;
  
              // Print received values for debugging
              // Uncomment the following lines if you want to output the values for debugging purposes
              
              Serial.print("Received: ");
              Serial.print("SG: "); Serial.print(serial_group_number);
              Serial.print(", Mode: "); Serial.print(is_start);
              Serial.print(", Addr: "); Serial.print(addr);
              Serial.print(", Duty: "); Serial.print(duty);
              Serial.print(", Freq: "); Serial.print(freq);
              Serial.print(", Wave: "); Serial.println(wave);
              
              
              sendCommand(serial_group_number, addr, is_start, duty, freq, wave);
          }
      }
      else{
          unsigned long timestamp = millis(); // Get current time in milliseconds
          Serial.print("Timestamp: ");
          Serial.print(timestamp);
          Serial.print(" ms, Data = ");
          Serial.print(value.length());
          Serial.print(", WRONG LENGTH!!!!!!!!!!!!!!!!");
      }
  }


    /* command format
        command = {
            'addr':motor_addr,
            'mode':start_or_stop,
            'duty':3, # default
            'freq':2, # default
            'wave':0, # default
        }
    */
    void sendCommand(int serial_group_number, int motor_addr, int is_start, int duty, int freq, int wave) {
//      uint8_t message = motor_addr;
//      serial_group[serial_group_number].write(message);
//      return;
      if (is_start == 1) { // Start command, two bytes
        uint8_t message[2];
        message[0] = (motor_addr << 1) | is_start;
        message[1] = 0x80 | (duty << 3) | (freq << 1) | wave;
        serial_group[serial_group_number].write(message, 2);
      } else { // Stop command, only one byte
        uint8_t message = (motor_addr << 1) | is_start;
        serial_group[serial_group_number].write(&message, 1);
      }
    }
};

class MyServerCallbacks: public BLEServerCallbacks {
    void onConnect(BLEServer* pServer, esp_ble_gatts_cb_param_t *param){
        Serial.println("connected!");
        Serial.println(BLEDevice::toString().c_str());
        char bda_str[18];
        sprintf(bda_str, "%02X:%02X:%02X:%02X:%02X:%02X", param->connect.remote_bda[0], param->connect.remote_bda[1], param->connect.remote_bda[2], param->connect.remote_bda[3], param->connect.remote_bda[4], param->connect.remote_bda[5]);
        Serial.println("Device connected with Address: " + String(bda_str));
        pServer->updateConnParams(param->connect.remote_bda, 0, 0, 0, 100);
        deviceConnected = true;
    }

    void onDisconnect(BLEServer* pServer) {
      Serial.println("disconnected!");
      delay(500);
      deviceConnected = false;
      BLEDevice::startAdvertising();
    }
};


void setup() {
  Serial.begin(500000);//even parity check
  //  pinMode(8, OUTPUT);
  //  pinMode(7, INPUT);
  //  Serial1.begin(115200, SERIAL_8E1);// Hardware Serial
  Serial.print("number of hardware serial available: ");
  Serial.println(SOC_UART_NUM);
  for (int i = 0; i < subchain_num; ++i) {
    Serial.print("initialize uart on GPIO");
    Serial.println(subchain_pins[i]);
    serial_group[i].begin(115200, SWSERIAL_8E1, -1, subchain_pins[i], false);
    serial_group[i].enableIntTx(false);
    if (!serial_group[i]) { // If the object did not initialize, then its configuration is invalid
      Serial.println("Invalid EspSoftwareSerial pin configuration, check config");
    }
    delay(200);
  }
  Serial.println("Starting BLE work!");

  // setup status LED (XIAO user LED on GPIO21 is active LOW: LOW = on)
  pinMode(STATUS_LED, OUTPUT);
  digitalWrite(STATUS_LED, LOW);   // turn LED on to indicate the board is ready

  //BLE setup
  BLEDevice::init("XIAO ESP32-S3");
  BLEServer *pServer = BLEDevice::createServer();
  pServer->setCallbacks(new MyServerCallbacks());
  BLEDevice::setMTU(128);
  BLEService *pService = pServer->createService(SERVICE_UUID);
  BLECharacteristic *pCharacteristic = pService->createCharacteristic(
                                         CHARACTERISTIC_UUID,
                                         BLECharacteristic::PROPERTY_READ |
                                         BLECharacteristic::PROPERTY_WRITE
                                       );
  pCharacteristic->setValue("0");
  pCharacteristic->setCallbacks(new MyCharacteristicCallbacks());
//  csCharacteristic = pService->createCharacteristic(
//                       CURRENTSENSING_UUID,
//                       BLECharacteristic::PROPERTY_READ
//                     );
//  csCharacteristic->setValue("0");

  pService->start();

  // BLEAdvertising *pAdvertising = pServer->getAdvertising();  // this still is working for backward compatibility
  BLEAdvertising *pAdvertising = BLEDevice::getAdvertising();
  pAdvertising->addServiceUUID(SERVICE_UUID);
  pAdvertising->setScanResponse(true);
//  pAdvertising->setMinPreferred(0x00);
//  pAdvertising->setMaxPreferred(0x00);
  BLEDevice::startAdvertising();
  Serial.println("Characteristic defined! Now you can read it in your phone!");

  //actuator pin setup
  //  for (int i=0; i<subchain_num; ++i){
  //    pinMode(subchain_pins[i], OUTPUT);
  //    digitalWrite(subchain_pins[i], LOW);
  //  }
//  pinMode(39, INPUT);   // NOTE: GPIO39 is not broken out on the XIAO base;
                          // pick a XIAO ADC pad (e.g. D0-D3 -> GPIO1-4) if re-enabling current sensing
}

void loop() {
  // put your main code here, to run repeatedly:
//  csCharacteristic->setValue(String(analogRead(39)).c_str());
//  delay(1000);
}

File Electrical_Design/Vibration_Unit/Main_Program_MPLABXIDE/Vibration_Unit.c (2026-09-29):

/* 
 * File:   main.c
 * Author: MasonC
 *
 * Created on November 8, 2022, 10:19 PM
 */

 #include <stdio.h>
 #include <stdlib.h>
 #include "neopixel_control.h"
 
 
 
 // PIC16F18313 Configuration Bit Settings
 
 // 'C' source line config statements
 
 // CONFIG1
 #pragma config FEXTOSC = OFF    // FEXTOSC External Oscillator mode Selection bits (Oscillator not enabled)
 #pragma config RSTOSC = HFINT32  // Power-up default value for COSC bits (HFINTOSC (1MHz))
 #pragma config CLKOUTEN = OFF   // Clock Out Enable bit (CLKOUT function is disabled; I/O or oscillator function on OSC2)
 #pragma config CSWEN = OFF      // Clock Switch Enable bit (The NOSC and NDIV bits cannot be changed by user software)
 #pragma config FCMEN = OFF      // Fail-Safe Clock Monitor Enable (Fail-Safe Clock Monitor is disabled)
 
 // CONFIG2
 #pragma config MCLRE = ON       // Master Clear Enable bit (MCLR/VPP pin function is MCLR; Weak pull-up enabled )
 #pragma config PWRTE = OFF      // Power-up Timer Enable bit (PWRT disabled)
 #pragma config WDTE = OFF       // Watchdog Timer Enable bits (WDT disabled; SWDTEN is ignored)
 #pragma config LPBOREN = OFF    // Low-power BOR enable bit (ULPBOR disabled)
 #pragma config BOREN = OFF      // Brown-out Reset Enable bits (Brown-out Reset disabled)
 #pragma config BORV = LOW       // Brown-out Reset Voltage selection bit (Brown-out voltage (Vbor) set to 2.45V)
 #pragma config PPS1WAY = OFF    // PPSLOCK bit One-Way Set Enable bit (The PPSLOCK bit can be set and cleared repeatedly (subject to the unlock sequence))
 #pragma config STVREN = ON      // Stack Overflow/Underflow Reset Enable bit (Stack Overflow or Underflow will cause a Reset)
 #pragma config DEBUG = OFF      // Debugger enable bit (Background debugger disabled)
 
 // CONFIG3
 #pragma config WRT = OFF        // User NVM self-write protection bits (Write protection off)
 #pragma config LVP = OFF         // Low Voltage Programming Enable bit (Low voltage programming enabled. MCLR/VPP pin function is MCLR. MCLRE configuration bit is ignored.)
 
 // CONFIG4
 #pragma config CP = OFF         // User NVM Program Memory Code Protection bit (User NVM code protection disabled)
 #pragma config CPD = OFF        // Data NVM Memory Code Protection bit (Data NVM code protection disabled)
 
 // #pragma config statements should precede project file includes.
 // Use project enums instead of #define for ON and OFF.
 #include <xc.h>
 #include <stdint.h>
 #include <stdlib.h>
 #define _XTAL_FREQ  32000000     // Set clock frequency 
 
 uint8_t buffer = 0;//uart recv buffer
 uint8_t parity = 0;//uart recv parity
 uint8_t uart_recv_flag = 0;
 
 uint8_t duty_index = 0; // 0-15 maps to PWM duty cycle 0-100%;
 uint8_t duty_cycle_array[] = {0,1,2,3,5,6,9,12,16,21,27,35,46,59,77,99};
 uint8_t duty_cycle = 0;
 uint8_t freq_index = 3; // 0-7 maps to frequency {116, 137, 164, 189, 222, 263, 303, 357} Hz;
 
 //uint8_t PR_val[] = {127, 107, 91, 78, 66, 56, 48, 40}; // PR2 values for frequencies;
 uint8_t PR_val[] = {85, 72, 60, 52, 44, 37, 32, 27}; // PR2 values for frequencies; f = 32 MHz / (4 * 4 * (PR2 + 1) * 200 steps)
 
 uint8_t ccp_flag = 0;
 uint8_t cwg_flag = 0;
 uint8_t duty_flag = 0;
 // Index into sine table
 uint8_t index = 0;
 uint8_t state = 0; //is the board being addressed by the controller
 
 // neopixel color
 uint8_t color_index = 0;
 uint8_t color[] = {0,0,0};
 
 void init_ccp_cwg(void) {
     // Set PA0, PA1 Pin as output
     TRISA0 = 1;//first set the flag to disable PA0 and PA1 outputs
     TRISA1 = 1;
     ANSELA = 0; // all digital
     WPUA = 0; // weak pullup
     //RA1PPS = 12; // Output CCP1 to RA1
     RA1PPS = 0b01000; //get cwg1a
     RA0PPS = 0b01001;//get cwg1b
     // Set CCP1CON register to PWM mode
     CCP1CON = 0b10011111;//FMT = 1
     CCP1IE = 1;
     // CCP1IF = 1;
     // Enable Global Interrupts
     GIE = 1;
     
     // Enable Peripheral Interrupts
     PEIE = 1;
     TMR2IE = 1; //enable interrupt on timer2
     // Set PR2 with appropriate PWM period
     
     // Set Timer2 Control Register
     T2CON = 0b00000001; // Timer 2 PS1/4 setting
     PR2 = PR_val[freq_index];
     
     //set cwg
   
     CWG1CON0 = 0b01000100;//half bridge, disable
     CWG1CON1 = 0;//A--non-invert, B--invert, C--non-invert, D--invert
     CWG1DAT = 0b00000011;//set data input to ccp1
     CWG1AS0 = 0b01111000;//disable autoshutdown, all 0 when shutdown occurs
     CWG1DBR = 0b0;
     CWG1DBF = 0b0;
     CWG1CLKCON = 1; //select hfint clk
     CWG1CON0bits.EN = 1;
     __delay_us(100);
 }
 
 void usart_init() {
     TRISA5 = 1; //port 5 as RXinput
     TRISA2 = 1; //port 2 as TXout
     ANSELA = 0;
     RXPPS = 0b00101; //port5 RX
     RA2PPS = 0b10100; //port2 TX
 
     RC1STA = 0b10010000; // 8 bit continuous reception CREN = 1 SPEN = 1
     TX1STA = 0b00100100; // Asynchronous reception High Baud Rate selection BRGH = 1  TXEN = 1; //transmit enable //async mode
     BAUD1CON = 0b00001000; // 16 bit SPBRG   BRG16 = 1
     SP1BRGH = 0;
     SP1BRGL = 68; // 115.2k baud rate
     TX9 = 1; //enable 9bit transmission
     RX9 = 1; //enable 9-bit recv
     RCIE = 1; //receive interrupt enable
     //IDLEN = 1; // Idle inhibits the CPU clk
 
     __delay_us(100); //wait for set up
 
 }
 uint8_t make_addr_byte(uint8_t start, uint8_t addr){
     //make the first, address byte for transmission
     uint8_t addr_byte = 0;
     addr_byte |= (start & 0b1);
     addr_byte |= (addr << 1);
    
     return addr_byte;
 }
 uint8_t getParity(uint8_t n)
 { //return the parity of n. if odd, return 1, even, return 0
     uint8_t parity = 0;
     while (n)
     {
         parity = !parity;
         n = n & (n - 1);
     }
     return (parity & 0b1);
 }
 
 void UART_Write(uint8_t data) {
     while(!TRMT){};
     
     TX9D = (getParity(data) & 0b1);
     TX1REG = data;
     
 }
 
 void UART_processing(){
     if(getParity(buffer) != parity) return; //drop packet 
     if((buffer >> 7) != 0b1){ //addr byte recved
         uint8_t addr = (buffer >> 1); //get addr
         uint8_t start = (buffer & 0b1); //get start/stop
         if(addr != 0){ //not the current address
             state = 0;// if state = 1 but the byte after is not data byte, then the unit should reset, to let commands go through.
             --addr; //decrease addr
             UART_Write(make_addr_byte(start, addr)); //send
             return;
         }
         else{ //the current addr
             state = start; 
             if(start == 0){
                 TMR2ON = 0;//ccp enable 
                 TRISA0 = 1;
                 TRISA1 = 1;
                 duty_index = 0;
             }
             return;
         }
     
     }
     else { //data byte received
         if(state == 0){ //previous data byte not address to this board
                 while(!TRMT){};
                 TX9D = parity & 0b1;
                 TX1REG = buffer;//transmit directly
                 return;
         }
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

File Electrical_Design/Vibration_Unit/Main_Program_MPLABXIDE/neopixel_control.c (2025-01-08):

#include "neopixel_control.h"

void SPI_Init(void)
{
    // Example: MSSP1 in SPI Master mode
    // SCK = Fosc / (4 * (SSP1ADD + 1)) in Mode 0
    // If we want 2.4 MHz, we solve for SSP1ADD:
    //   2.4e6 = 32e6 / (4*(SSP1ADD + 1))
    //   32e6 / 2.4e6 = 13.3333 = 4*(SSP1ADD + 1)
    //   (SSP1ADD + 1) = 13.3333 / 4 = 3.3333
    //   SSP1ADD ? 2.33
    // We must pick an integer, so let's pick SSP1ADD=2 => 2.666 MHz (close enough!)
    // or SSP1ADD=3 => 2.0 MHz.  Either can work.

    SSP1ADD  = 2;        // This yields ~2.67 MHz (a bit above 2.4, typically still OK)
    SSP1CON1 = 0b00101010;     // SSPEN=1 (enable), CKP=0 (Idle low), SSPM=b1010 (Master Fosc/(4*(SSPxADD+1)))
    SSP1STAT = 0b00000000;     // CKE=1 (transmit on active->idle)
    
    // TRIS setup: SDO is output
    // On PIC16F18313, check datasheet for pin assignment
    TRISA4 = 0;  // configure RA4 as output (SDO)
    RA4PPS = 0b11001; // RA4 is SDO1 (SPI1 data out)
    // Remap pins if needed (APFCON, etc.). Check your PIC16F18313 pinout.
}

// inputByte = 8 bits to send to WS2812
// outArray must have space for 3 bytes (24 bits).
// We'll store them in big-endian or little-endian order as convenient.
void encodeByte(uint8_t inputByte, uint8_t outArray[4])
{
    uint8_t i;
    uint32_t encoded = 0; // We'll build up 24 bits

    // Build from MSB to LSB of inputByte
    for(i = 0; i < 8; i++)
    {
        if (i % 2 == 0){
            encoded <<= 2;
        }
        encoded <<= 3; // Make room for 3 new bits
        if (inputByte & 0x80)
        {
            // bit = '1'
            encoded |= WS2812_1;
        }
        else
        {
            // bit = '0'
            encoded |= WS2812_0;
        }
        inputByte <<= 1; // Next bit
    }

    // Now we have 24 bits in 'encoded'. Split into 3 bytes
    // The top 8 bits are (encoded >> 16), then >> 8, then low 8 bits
    outArray[0] = (uint8_t)( (encoded >> 24) & 0xFF );
    outArray[1] = (uint8_t)( (encoded >> 16) & 0xFF );
    outArray[2] = (uint8_t)( (encoded >>  8) & 0xFF );
    outArray[3] = (uint8_t)(  encoded        & 0xFF );
}

void sendColor_SPI(uint8_t g, uint8_t r, uint8_t b)
{
    uint8_t gEnc[4], rEnc[4], bEnc[4];
    encodeByte(g, gEnc);
    encodeByte(r, rEnc);
    encodeByte(b, bEnc);

    // Total 9 bytes to send for 24 bits color
    // G -> 3 bytes, R -> 3 bytes, B -> 3 bytes
    // Wait for SPI idle, then write them out.
    for(uint8_t i = 0; i < 4; i++)
    {
        SSP1BUF = gEnc[i];
        while(!SSP1STATbits.BF);  // Wait
    }
    for(uint8_t i = 0; i < 4; i++)
    {
        SSP1BUF = rEnc[i];
        while(!SSP1STATbits.BF);  // Wait
    }
    for(uint8_t i = 0; i < 4; i++)
    {
        SSP1BUF = bEnc[i];
        while(!SSP1STATbits.BF);  // Wait
    }

    // After finishing all bytes, we do a latch/reset by holding line low ~50us.
    // With SPI, usually the line idles at low if CKP=0, so just wait in software:
    __delay_us(60);  // ~60us is enough for the WS2812 to latch
}

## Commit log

2025-01-07 add bambulab printing file
2025-01-08 neopixel control functioning now, with minor issues
    [Vibration_Unit.c, neopixel_control.c]
2025-01-28 refactor vibration unit program to make it more robust
    [Vibration_Unit.c]
2025-01-29 fix TMR2IF and CCP1IF issue
    [Vibration_Unit.c]
2025-02-18 fix uart bug
2025-05-29 update PCB design files with NeoPixels
    [Board_LRA_Altium.pcbdoc, Board_LRA_BOM.csv, Board_VCA_Altium.pcbdoc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]
2025-06-17 add BOM and CPL files for PCB production
    [Board_Small_Unit_BOM.csv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]
2025-06-19 add pcb files for control unit board
    [Board_Small_Unit_BOM.csv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]
2025-06-20 fix led not turn off bug
    [app.py]
2025-07-16 update small control unit PCB to ver 1.3
    [Board_Small_Unit_Altium.pcbdoc, Schematic_Small_Unit_Altium.schdoc]
2025-09-01 update small control unit enclosure stl file ;
    [Enclosure.stl]
2025-09-21 update LRAX unit mechanical design
    [Cap.3mf, Cap.stl, Enclosure.stl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]
2026-07-16 significant improvement on documentation, add support for XIAOESP32S3
    [Cap.3mf, VibraForge Dev Kit BOM.csv]
2026-09-29 Move standalone NeoPixel test out of the firmware sources
    Neopixel_Test.c defines its own main(), so it cannot be built alongside
    Vibration_Unit.c. Keep it under tests/ so the firmware folder only holds
    the files that go into the MPLAB X project.
    [Neopixel_Test.c]
2026-09-29 Update vibration frequency table to match NeoPixel firmware timing
    The NeoPixel firmware (d10370e) switched Timer2 to a 1:4 prescaler, new
    PR2 values, and a 200-step vibration period, which shifted the eight
    frequency levels to 116-357 Hz. The GUI and the firmware comment still
    listed the old 123-384 Hz values, so the GUI mapped requested
    frequencies to the wrong index.
    Firmware behavior is unchanged; only the GUI lookup table and comments
    are updated, and the formula is documented next to PR_val.
    [Vibration_Unit.c, app.py]
2026-09-29 Update docs for the NeoPixel vibration board
    - Status LED: the vibration boards now carry a single RGB NeoPixel that
    is off when idle and lights with an intensity-dependent color on Start
    (replaces the two-LED description; it no longer indicates power)
    - Firmware: list neopixel_control.c/.h alongside Vibration_Unit.c,
    explain which files go into the MPLAB X project, drop the outdated
    "watchdog enabled" note
    - Ordering: vibration PCBs now ship with JLCPCB BOM/CPL files
2026-09-29 Add battery-free control unit enclosure and cap
    Adds a slimmer enclosure and cap for a small control unit powered over
    USB with no battery (STL for printing plus editable STEP files).
    The existing battery design is kept and renamed to *_with_Battery.stl so
    the two variants are easy to tell apart. The Mechanical_Design readme
    now describes both variants and how they differ.
    [Cap_Battery_Free.step, Cap_Battery_Free.stl, Cap_with_Battery.stl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]
2026-09-29 Use the battery-free control unit enclosure in the dev kit
    Point the manufacturing guide (flowchart, BOM table, print step,
    checklist) and the dev kit BOM at Enclosure_Battery_Free.stl and
    Cap_Battery_Free.stl, and mark the battery-free variant as the dev kit
    choice in the Mechanical_Design readme.
    [VibraForge Dev Kit BOM.csv]
2026-11-05 Add sine/square vibration firmware, 3-byte controller, and BLE sweep test
    - buck_main.c: PIC16F18313 firmware with a sine (sPWM) mode alongside
    square, 32 intensity levels through calibrated LUTs, and an 8N1 UART
    protocol with 3-byte start commands. Copied unchanged from the MPLAB
    project; Vibration_Unit.c (square only) is kept as is.
    - BLE_3bytes_ESP32: controller sketch that turns 3-byte BLE frames
    (wave, group, mode / address / duty5, freq3) into the new PIC commands.
    - Python_Sine_Test.py: bleak script that ramps one board from intensity
    0 to 31 in 8 s, with step-by-step debug output.
2026-11-05 Calibrate sine Timer1 reloads against measured frequencies
    Indexes 0-3 measured 119.6, 140.5, 163.3 and 191.1 Hz with the old
    reloads, about 3.6 us per step longer than 65536 - reload because the
    ISR rewrites Timer1 after its entry latency. The new reloads subtract
    that latency so the sine hits 123, 145, 170, 200, 235, 275, 322 and
    384 Hz (indexes 4-7 are extrapolated from 0-3).
2026-11-05 Brake the motor driver when stopped instead of coasting
    A stop (and power-up) left IN1 = IN2 = 0, which puts the DRV8837 in
    coast: OUT1/OUT2 float and the actuator picks up 50 Hz mains hum.
    Driving IN1 = IN2 = 1 brakes instead, holding both outputs low.
2026-11-06 Remove unused ArduinoJson include from the control unit sketches
    The BLE peripheral sketches parse commands as raw 3-byte binary frames
    and never use ArduinoJson, so drop the include and stop listing it as a
    required library in the manufacturing guide.
2026-11-06 Precompute sine amplitude tables outside the Timer1 ISR
    The Timer1 ISR did a 32-bit software multiply and shift every sine step,
    about 610 instruction cycles (76 us), which capped sine at ~205 Hz and
    pinned frequency indexes 4-7 there. A sine command now hands the
    amplitude to main(), which builds the 17 quarter-wave PWM compare values
    (CCPR1H/CCPR1L) and then starts Timer1; the ISR only looks them up
    (~14-19 us per step). Interrupts stay on while the table is built, so
    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
2026-11-06 Add a square-wave BLE sweep test for the main-branch controller
    Python_Square_Test.py mirrors Python_Sine_Test.py but talks to the
    QT Py ESP32-S3 controller with main's command format (16 duty levels,
    3-bit frequency index, frames padded to 20 like Python_Test.py). It was
    used to confirm the square firmware runs at its nominal 116-357 Hz.
    FREQ in both test scripts is left at the last value used.
2026-11-06 Restore the 123-384 Hz frequency set in the GUI and firmware comment
    Reverts ae9a572. 123, 145, 170, 200, 235, 275, 322, 384 Hz (log-spaced,
    ~17.5% steps) is the set the vibration firmware was designed for in
    ed6a47d. The square firmware only drifted to 116-357 Hz when d10370e
    moved to 200 steps per cycle with PR2 values ~5% too high, and ae9a572
    then changed the GUI to match that drift. The sine firmware that
    replaces the square wave next is calibrated to 123-384 Hz.
2026-11-06 Drive the vibration unit with an SPWM sine instead of a square wave
    Vibration_Unit.c now drives the actuator with the 64-step sine from the
    sine-wave-test prototype (SPWM on a 40 kHz carrier, steps timed by
    Timer1) and keeps main's serial protocol unchanged: 115200 baud, 9 bits
    with even parity, address byte [0][addr6][start] plus data byte
    [1][duty4][freq3], and daisy-chain forwarding. Main's
    BLE_peripheral_QTPyS3 controller and host scripts work as before.
    - 8 frequencies: 123, 145, 170, 200, 235, 275, 322, 384 Hz from the
    calibrated T1_RELOAD values. The ISR path to the Timer1 reload is the
    same 27 cycles the calibration was measured with.
    - 16 intensities: the old duty numbers becom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
2026-11-06 Remove the 3-byte sine prototype and turn the square test into a sweep test
    buck_main.c, BLE_3bytes_ESP32.ino and Python_Sine_Test.py used a
    separate 8N1, 3-byte command protocol that is no longer needed now that
    Vibration_Unit.c runs the sine on main's protocol. Python_Square_Test.py
    already speaks main's protocol, so it becomes Python_Sweep_Test.py with
    log labels for the sine firmware (amplitude per intensity, 123-384 Hz).
2026-11-06 Document the ESP32 core version the control unit sketch needs
    BLE_peripheral_QTPyS3.ino uses the Bluedroid onConnect(BLEServer*,
    esp_ble_gatts_cb_param_t*) callback. From arduino-esp32 3.3.0 the
    ESP32-S3 builds with NimBLE instead, and the sketch no longer compiles.
    The guide now says to use core 3.2.1 or earlier, lists the tested
    library versions, and names the board entry for the #5426 QT Py
    (8 MB flash, no PSRAM).

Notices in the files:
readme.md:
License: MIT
